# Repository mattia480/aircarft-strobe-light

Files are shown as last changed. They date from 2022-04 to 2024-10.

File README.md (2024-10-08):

# Arduino Strobe Light Circuit and Diagram for Ultralight Aircraft

This repository contains a simple blueprint, including schematics, diagrams and code for the installation of LED strobe lights (winglets and tail) on ultralight aircraft or for general aviation aircraft classified as experimental.

Each lamp is made up of at least one series of 3 high power 3W LEDs powered directly at 12-14 Volts.

Prototype PCBs with aluminum base have been created for the lamps for better heat dissipation (thanks to JLCPCB).

The LEDs used are [HL-EF13W3NAMS (Ra2)](https://lcsc.com/product-detail/Light-Emitting-Diodes-LED_HONGLITRONIC-Hongli-Zhihui-HONGLITRONIC-HL-EF13W3NAMS-Ra2_C784723.html) in which for each series of 3 a SMD type rectifier diode (SMC) code [S5G](https://lcsc.com/product-detail/Diodes-Fast-Recovery-Rectifiers_Shandong-Jingdao-Microelectronics-ES5GC_C128705.html) has been added to avoid polarity inversions.

Gerber files are available for download within the repository.

#### Circuit Diagram

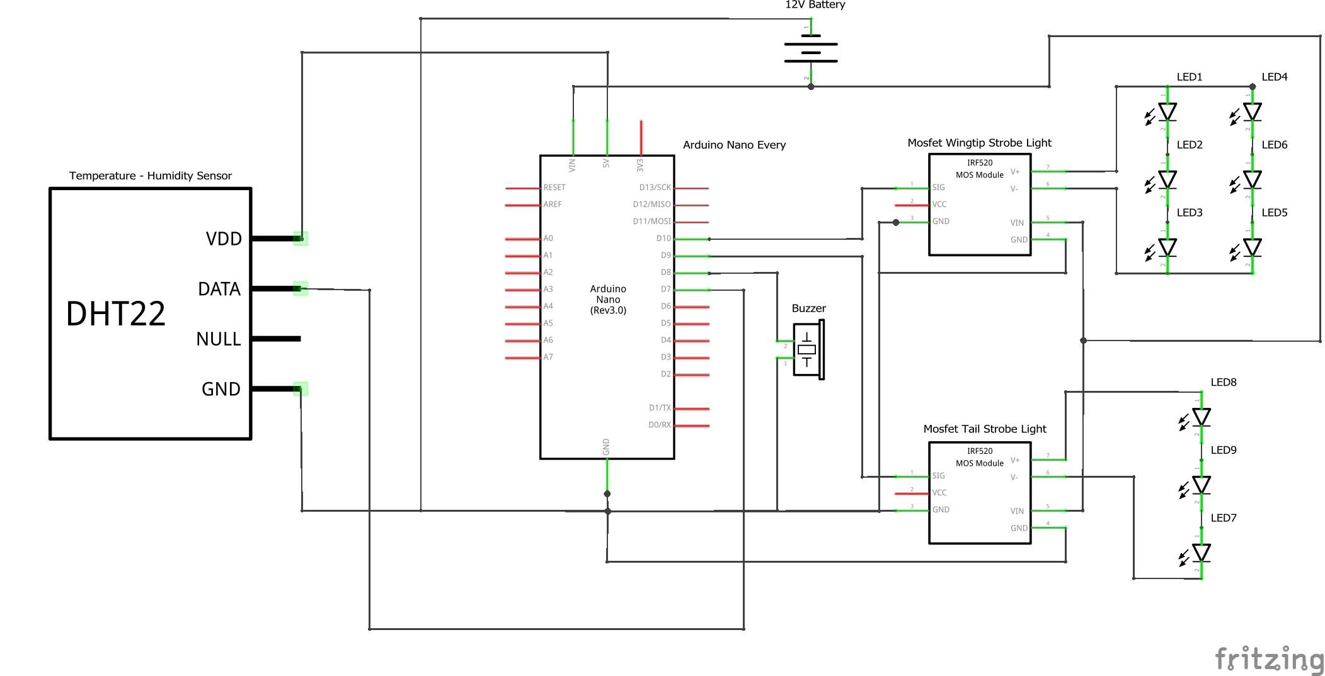
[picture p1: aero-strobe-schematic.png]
Circuit Diagaram


#### Components
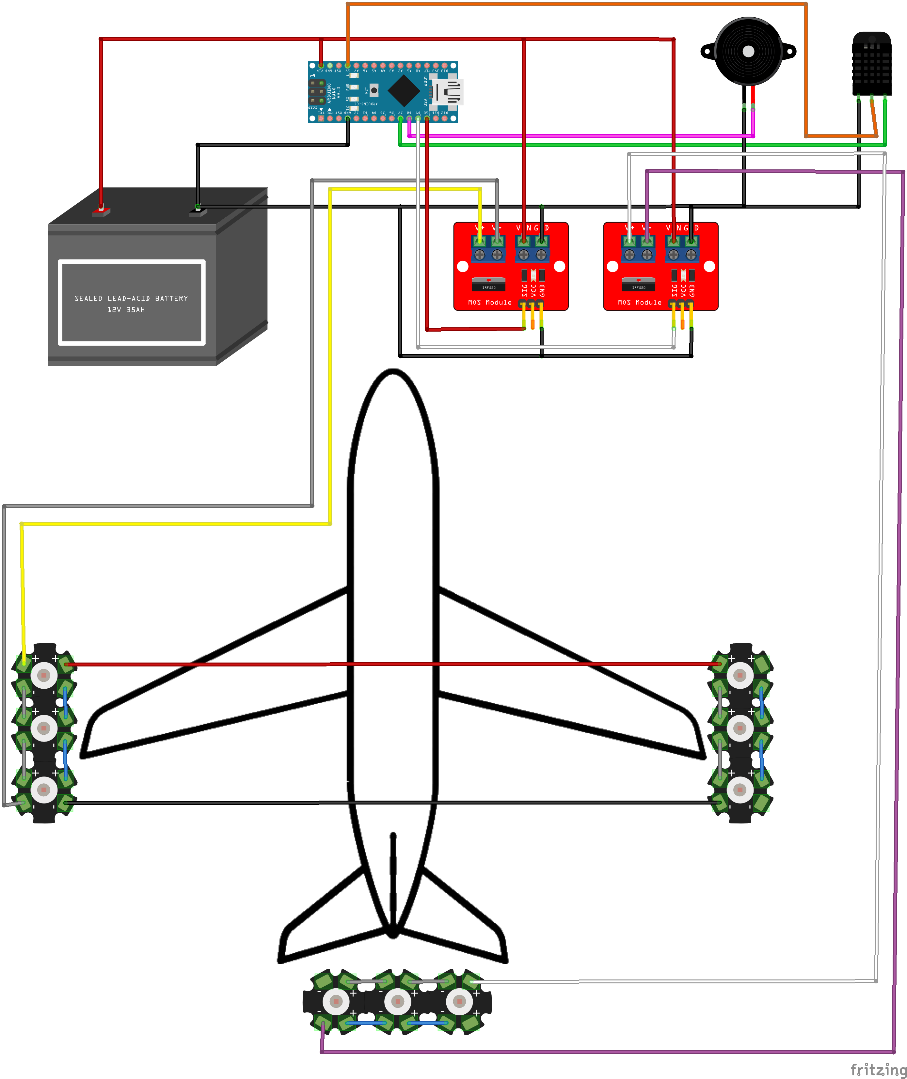
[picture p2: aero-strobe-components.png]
Components


#### Top PCB Design
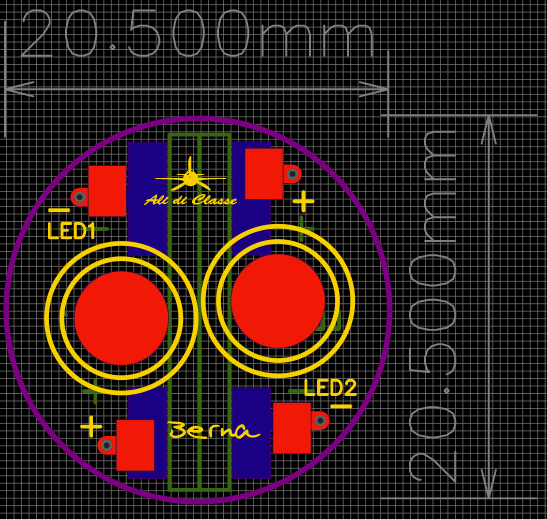
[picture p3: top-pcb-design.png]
Top PCB Design


#### Top PCB Front Side
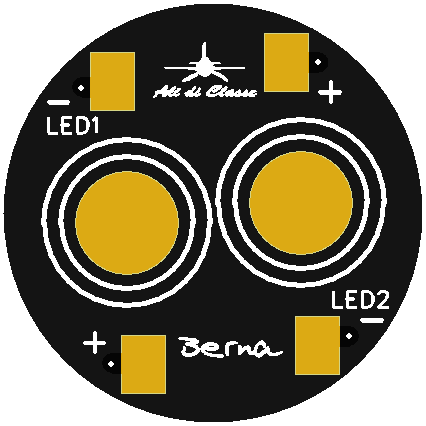
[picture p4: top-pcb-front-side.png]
Top PCB Front Side


#### Top PCB Back Side
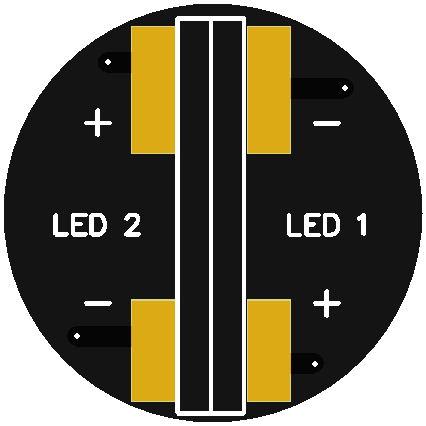
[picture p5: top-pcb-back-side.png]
Top PCB Back Side


#### Side PCB Design
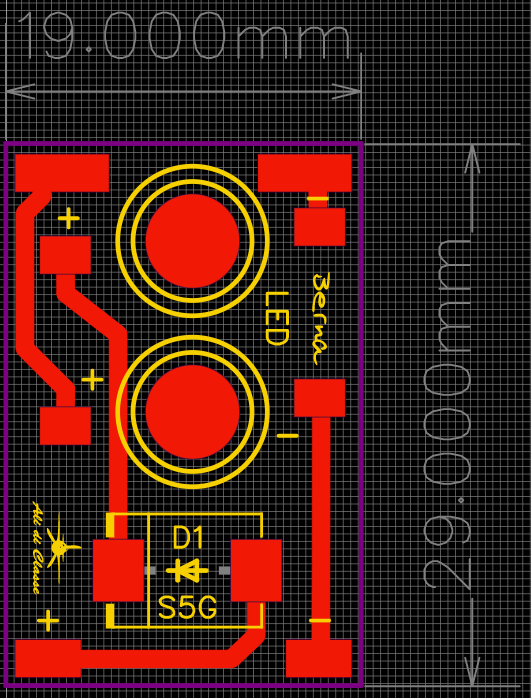
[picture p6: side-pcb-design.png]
Side PCB Design


#### Side PCB
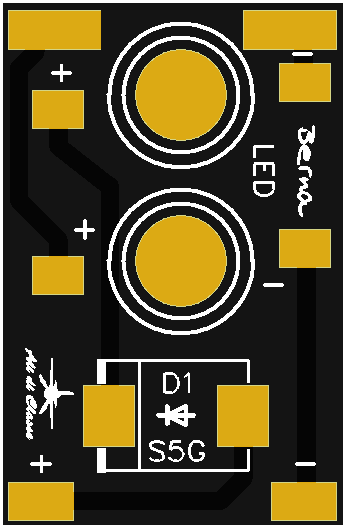
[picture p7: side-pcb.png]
Side PCB


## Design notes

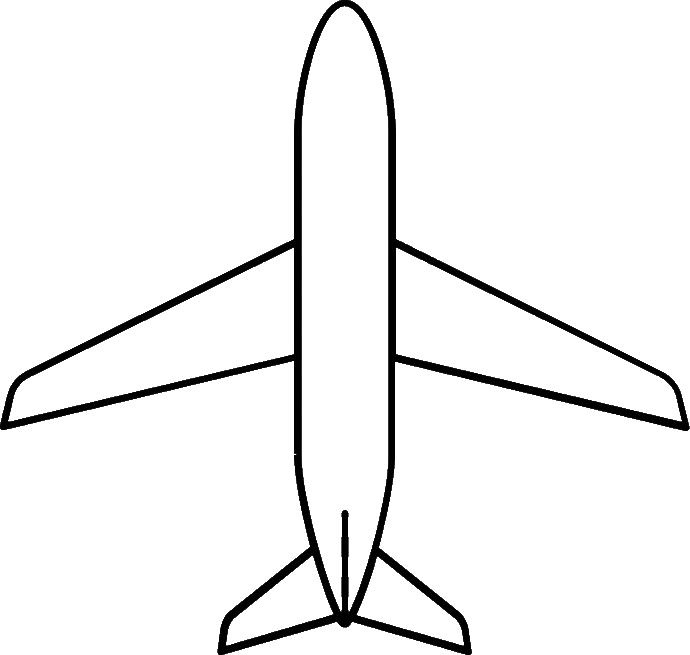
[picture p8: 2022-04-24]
aircraft.png

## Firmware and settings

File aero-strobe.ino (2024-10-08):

/**
 * Arduino Strobe Light for Ultralight Aircraft
 * =====================
 *
 * @author      Current authors: Ing. Mattia Bernasconi <mattia@studiobernasconi.com>
 *              Original author: Ing. Mattia Bernasconi <mattia@studiobernasconi.com>
 * 
 * @versione    1.1.1
 *
 * @license     GNU General Public License v3.0
 *
 * @link        Homepage: http://www.mattiabernasconi.it
 * 
 * @date        2022-05-08
 * 
 * If "MULTI_MODE_ENABLED" variable is set to true, by powering on and off the device quickly (1.5 second), we can change the operating mode
 * Mode 1 (Standard) -> Wingtip flash "WINGTIP_STROBE_NUM" and Tail flash "TAIL_STROBE_NUM" every "TIME_BETWEEN_STROBE" millis
 * Mode 2            -> Wingtip flash "WINGTIP_STROBE_NUM" and Tail flash "TAIL_STROBE_NUM" every "TIME_BETWEEN_STROBE" millis but Tail Strobe remain at "MODE2_TAIL_BRIGHTNESS" all the time
 * Mode 3            -> Same at Mode 1 but disable temperature check (in case of needed while flyng, i.e. during hot day in summer if "TEMP_ERROR" is set too low)
 * 
 * 3 tones at startup indicate I2C error
 * 6 tones at startup indicate DHT error
 * 
 * N tones after startup indicate mode N selecetd (if "MULTI_MODE_ENABLED" variable is set to true)
 * 
 * Address 500 of I2C EEPROM is used to count DHT error
 * 
 * Serial enabled at baude rate 9600
 */

#define DEBUG // Comment to remove serial debug messages

// Include the Arduino's internal EEPROM Libray
#include <EEPROM.h>

// Include the I2C Wire Library
#include <Wire.h>

// Include the DHT Library
#include <DHT.h>;

// EEPROM I2C Address
#define EEPROM_I2C_ADDRESS 0x50

//DHT PIN
#define DHTPIN 7

//DHT TYPE 21 (AM2301)
#define DHTTYPE DHT21

// Set user editable variables
const bool MULTI_MODE_ENABLED = true; // Enable multi mode switching by power
const bool TEMP_CHECK_ENABLED = true; // Enable system temperature check
const float TEMP_ERROR = 60.0; // Temperature to put the system in protection mode
const int MODE2_TAIL_BRIGHTNESS = 22; // Brightness of Tail light (0-255)
const int WINGTIP_STROBE_NUM = 2; // Number of Wingtip flash
const int TAIL_STROBE_NUM = 1; // Number of Tail flash
const int TIME_BETWEEN_STROBE = 1600; // Time between flashes (in millis)

// Set system configuration variables
int strobe_wingtip = 10;
int strobe_tail = 9; 
int beacon = 6;
int buzzer = 8;

int multi_mode_selector = 0; // Multi mode selector
int MULTI_MODE_EEPROM_ADDR = 0; // Multi mode EEPROM address
int dht_error = 0; // DHT error
int TEMP_ERROR_EEPROM_ADDRESS = 500; //EEPROM Address used to count DHT error

// Initialize DHT sensor for normal 16mhz Arduino
DHT dht(DHTPIN, DHTTYPE);

// Function to write to I2C EEPROOM
void i2cWriteEEPROM(int address, byte val)
{
  // Begin transmission to I2C EEPROM
  Wire.beginTransmission(EEPROM_I2C_ADDRESS);

  // Send memory address as two 8-bit bytes
  Wire.write((int)(address >> 8));   // MSB
  Wire.write((int)(address & 0xFF)); // LSB

  // Send data to be stored
  Wire.write(val);

  // End the transmission
  Wire.endTransmission();

  // Add 5ms delay for EEPROM
  delay(5);
}

// Function to read from I2C EEPROOM
byte i2cReadEEPROM(int address)
{
  // Define byte for received data
  byte rcvData = 0xFF;

  // Begin transmission to I2C EEPROM
  Wire.beginTransmission(EEPROM_I2C_ADDRESS);

  // Send memory address as two 8-bit bytes
  Wire.write((int)(address >> 8));   // MSB
  Wire.write((int)(address & 0xFF)); // LSB

  // End the transmission
  Wire.endTransmission();

  // Request one byte of data at current memory address
  Wire.requestFrom(EEPROM_I2C_ADDRESS, 1);

  // Read the data and assign to variable
  rcvData =  Wire.read();

  // Return the data as function output
  return rcvData;
}

// Function to check external temp and block the system if temp is over TEMP_ERROR user's value
void tempCheck() {
  // First temperature and humidity read
  float hum = dht.readHumidity();
  float temp = dht.readTemperature();

  // Check if any reads failed and increment error counter
  if (isnan(hum) || isnan(temp)) {
    Serial.println(F("Failed to read from DHT sensor!"));
    dht_error++;
  } else {
    dht_error = 0;
  }

  // Write error into external EEPROM
  if(dht_error == 1) {
    int eeprom_temp_error = i2cReadEEPROM(TEMP_ERROR_EEPROM_ADDRESS);
    eeprom_temp_error++;
    i2cWriteEEPROM(TEMP_ERROR_EEPROM_ADDRESS, eeprom_temp_error);
  }

  // If the DHT sensor is in error for more than 15 times (30sec) or there is an overtemperature stop the system
  if (dht_error >= 15 || temp >= TEMP_ERROR) {
    unsigned long error_time = (millis() / 1000);
    do {
      temp = dht.readTemperature();
      Serial.println(F("The temperature is too high or DHT sensor is unavailable!"));
      Serial.print("Current reading temperature: "); Serial.print(temp);
      Serial.println(" Celsius");
      
      // Turn on buzzer
      digitalWrite(buzzer, HIGH);
      delay(500);
      // Turn off buzzer
      digitalWrite(buzzer, LOW);

      // Wait 1 second before read again
      delay(1000);

      // If more than 3 minutes have passed turn on the buzzer to notify the problem
      if ((millis() / 1000) - error_time > 180) {
        // Turn on buzzer for at least 5 minutes
        digitalWrite(buzzer, HIGH);
        delay(300000);
      }
    } while (temp >= TEMP_ERROR);

    // Turn off buzzer
    digitalWrite(buzzer, LOW);
  }
  
  // Print temp and humidity values to serial monitor if debug enabled
  #ifdef DEBUG
  Serial.print("Humidity: ");
  Serial.print(hum);
  Serial.print("%, Temperature: ");
  Serial.print(temp);
  Serial.println(" Celsius");
  #endif
}

// Setup digital pin and peripherals
void setup() {
  Serial.begin(9600);
  Serial.println("System is starting up. Please wait...");

  // Connect to I2C BUS as Master
  Wire.begin();

  // Initizalize DHT sensor
  dht.begin();

  // Initialize digital pin
  pinMode(LED_BUILTIN, OUTPUT);
  pinMode(strobe_wingtip, OUTPUT);
  pinMode(strobe_tail, OUTPUT);
  pinMode(beacon, OUTPUT);
  pinMode(buzzer, OUTPUT);

  // Switch off all output
  digitalWrite(strobe_wingtip, LOW);
  digitalWrite(strobe_tail, LOW);
  digitalWrite(beacon, LOW);
  digitalWrite(buzzer, LOW);

  // Check I2C EEPROM Connection
  Wire.beginTransmission(EEPROM_I2C_ADDRESS);
  byte i2c_eeprom_error = Wire.endTransmission();
  if (i2c_eeprom_error == 0) {
    Serial.println("I2C EEPROM device OK!");
  } else {
    Serial.println("I2C EEPROM device not found!");
    // Tone 3 time to declare I2C EEPROM Error 
    for (int i = 0; i < 3; i++) {
      digitalWrite(buzzer, HIGH);
      delay(150);
      digitalWrite(buzzer, LOW);
      delay(150);
    }
  }
  
  // If multi mode enabled save and read state to/from EEPROM
  if (MULTI_MODE_ENABLED) {
    // External EEPROM is available
    if (i2c_eeprom_error == 0) {
      // Read EEPROM
      multi_mode_selector = i2cReadEEPROM(MULTI_MODE_EEPROM_ADDR);
      // Increment mode readed
      multi_mode_selector++;

      // Write actual mode to EEPROM
      i2cWriteEEPROM(MULTI_MODE_EEPROM_ADDR, multi_mode_selector);

      // After 1 second we can safely put to mode 0 (standard)
      delay(1100);
      i2cWriteEEPROM(MULTI_MODE_EEPROM_ADDR, 0);
    } else {
      // Read EEPROM
      multi_mode_selector = EEPROM.read(MULTI_MODE_EEPROM_ADDR);
      // Increment mode readed
      multi_mode_selector++;

      // Write actual mode to EEPROM
      EEPROM.update(MULTI_MODE_EEPROM_ADDR, multi_mode_selector);

      // After 1 second we can safely put to mode 0 (standard)
      delay(1100);
      EEPROM.update(MULTI_MODE_EEPROM_ADDR, 0);
    }
  } else {
    delay(500); // Fix DHT startup on Nano Every
  }

  // Check DHT Sensor
  if (dht.read(true) != 0) {
    Serial.println("DHT device OK!");
    Serial.print("DHT Error counter read from EEPROM: ");
    Serial.println(i2cReadEEPROM(TEMP_ERROR_EEPROM_ADDRESS));
  } else {
    Serial.println("DHT device not found!");
    // Tone 6 time to declare DHT device error 
    for (int i = 0; i < 6; i++) {
      digitalWrite(buzzer, HIGH);
      delay(150);
      digitalWrite(buzzer, LOW);
      delay(150);
    }
  }

  // Buzzer sound of mode enabled
  for (int i = 0; i < multi_mode_selector; i++) {
    digitalWrite(buzzer, HIGH);
    delay(200);
    digitalWrite(buzzer, LOW);
    delay(150);
  }

  Serial.println("System startup complete!");
  Serial.print("Mode ");
  Serial.print(multi_mode_selector);
  Serial.println(" selected");
}

void loop() {
  // Arduino LED On
  digitalWrite(LED_BUILTIN, HIGH);

  // Check temperature before flash (if enabled)
  if (TEMP_CHECK_ENABLED && multi_mode_selector != 3)
    tempCheck();
  
  // Wingtip flash
  for (int i = 0; i < WINGTIP_STROBE_NUM; i++) {
    digitalWrite(strobe_wingtip, HIGH);
    delay(70);
    digitalWrite(strobe_wingtip, LOW);
    if (i+1 < WINGTIP_STROBE_NUM)
      delay(70);
  }

  // Tail flash
  for (int i = 0; i < TAIL_STROBE_NUM; i++) {
    digitalWrite(strobe_tail, HIGH);
    delay(70);
    digitalWrite(strobe_tail, LOW);
    if (i+1 < TAIL_STROBE_NUM)
      delay(70);
  }
  if (multi_mode_selector == 2) {
    analogWrite(strobe_tail, MODE2_TAIL_BRIGHTNESS);
  } else {
    digitalWrite(strobe_tail, LOW);
  }

  // Arduino LED Off
  digitalWrite(LED_BUILTIN, LOW);

  // Delay after flash
  delay(TIME_BETWEEN_STROBE);
}

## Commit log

2022-04-24 First release of code, circuit and diagram
    [aero-strobe-schema.fzz]
2022-04-24 Add PCB image and gerber files
2022-04-27 Code V 1.1 with temp sensor, buzzer and I2C EEPROM
    [aero-strobe.ino]
2022-05-08 DHT fix for Arduino Nano Every
    [aero-strobe.ino]
